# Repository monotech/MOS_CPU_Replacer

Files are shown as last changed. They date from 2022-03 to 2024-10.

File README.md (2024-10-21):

# Monotech PCs - MOS CPU Replacer  
**Replace rare/expensive/unreliable MOS CPUs**  
6510 *(C64) (8500 is same as 6510)*  
6510T *(1551 floppy drive)*  
8501 *(C16, C116, Plus/4) (7501 is same as 8501)*  
8502 *(C128)*

Licensed under Creative Commons BY-SA: (https://creativecommons.org/licenses/by-sa/4.0/)

If you want one, check my store for stock: (https://monotech.fwscart.com)

The above four CPUs have the same dies I believe, with just different internal pads exposed to the DIP-40 pins.  
It's a standard 6502 die, with an added 8-bit bidirectional I/O port, tri-state bus buffers, and an AEC latch enable for 8501 mode.

This device uses a standard 6502 CPU, and implements the extra functions using discrete logic - no programmable parts.  
Standard 6502 CPUs are abundant and cheap, and produced by many manufacturers (Rockwell, UMC, Synertek, MOS, etc).

You can use a 65C02 or W65C02, but this is untested, and will cause compatibility issues with some software at the least, or not work at the worst.  
If using a WDC W65C02, you must cut jumper W.

Build instructions are on the back of the PCB. This document is for clarification if you find it unclear.

It may struggle to fit inside a C116 or Plus/4 due to height, so for these machines you should solder the 6502 directly to the module's PCB, or solder the module directly to the C116 or Plus/4 motherboard.  
For C16, height is not a problem.

It is tested to fit next to a PLA20V8 replacement in a 250407 board. Other oversized replacement boards may interfere and require installing the module in an extra socket to raise it up.

Status as of Rev1:
-

- :heavy_check_mark: 6510 config: Tested working in a C64 and C64C with a wide range of software. In one scenario, it was discovered that it causes graphical glitches when used in a C64 with a C0pperdragon video conversion device (which watches the VIC-II pins). This was on Rev1. It may or may not be resolved on Rev2.
- :heavy_check_mark: 6510T config: I don't have a 1551, but someone else has done some basic testing in their own, and it works.
- :x: 8501 config: Tested working in a C16 and a Plus/4, but it has been found that at least one program crashes on a 64K-modded C16, that doesn't crash with a real 8501.
- :x: 8502 config: Works but has graphical glitches, likely due to a timing issue, so should only be built if you plan to help me diagnose this. For 8502, you must install a 2MHz-rated CPU (such as 6502A).

Known issues:
-

- A local enthusiast has discovered that using this adapter in 8501 config in their 64K-modded C16, results in Slipstream (https://psytronik.itch.io/slipstream) hanging, and causing resets to stop working (need a power cycle). One other person has confirmed this, and confirmed it doesn't happen with a real 8501, so the issue is with the MOS CPU Replacer. I will look into possible causes and update this page if a solution is found. Testing the C64 version of Slipstream in a C64 works fine with either a real 6510 or the MOS CPU Replacer in 6510 config.
- One user reported that it causes graphical glitches when used in a C64 (6510 config) with a C0pperdragon video conversion device (which watches the VIC-II pins), but works well otherwise. This was on Rev1. It may or may not be resolved on Rev2.
- I am sometimes working on improving the device, and hopefully reaching 100% compatibility.

---
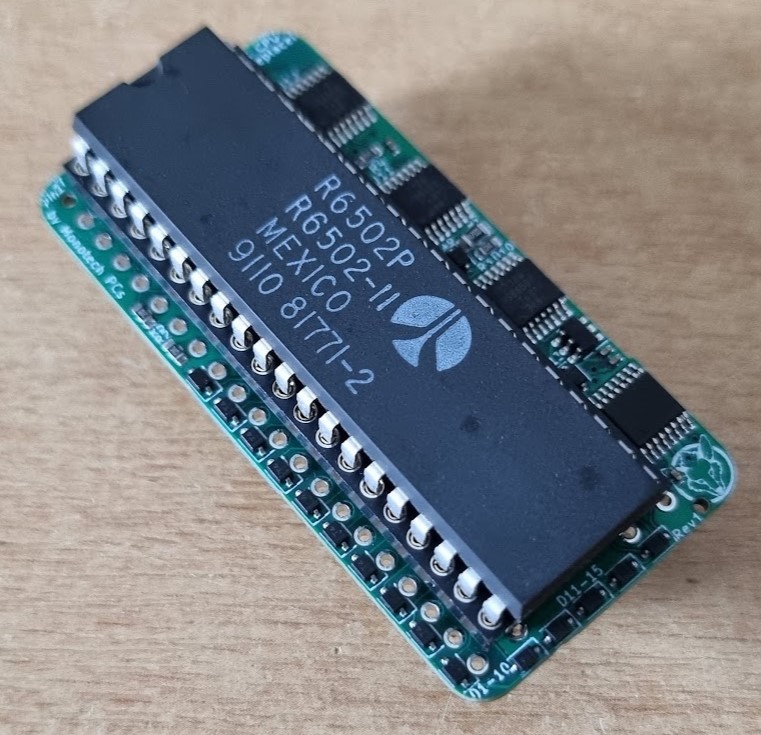
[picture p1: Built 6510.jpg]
Built in 6510 config


Instructions:
-

1. Solder the solder-jumpers first (red dots).
1. Solder two 20-pin round-pin headers (cyan rectangles). (Not 21-pin!)
1. Solder the DIP-40 socket (yellow rectangles).
1. Install the 6502, and test the device.
    Don't install the device backwards or misaligned!

**The example picture below is for 8501 config (Jumpers: C, Headers: E). Steps 1 and 2 are different for the other three configs.**

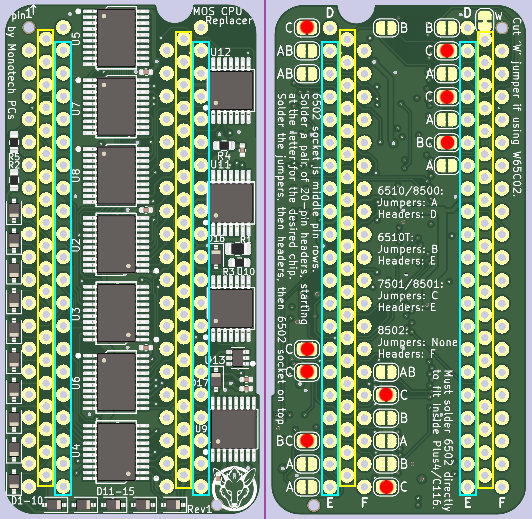
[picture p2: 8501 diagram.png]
Diagram for 8501 config


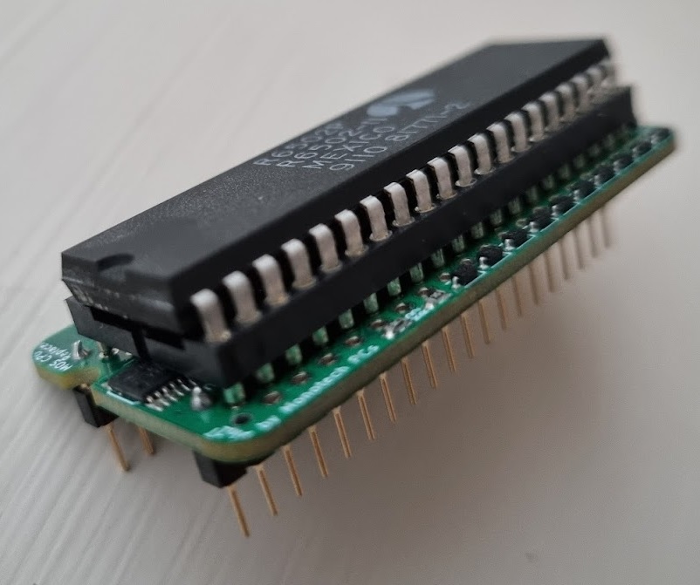
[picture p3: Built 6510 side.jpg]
Built in 6510 config, side view


**Troubleshooting**

- See the Known Issues section above.
- Double-check for shorts and that you soldered the correct solder jumpers.
- Crappy single-wipe IC sockets that Commodore used, can cause a lot of headache. Replace them.
- Your 6502 from Aliexpress/eBay may be fake or faulty. Sometimes they are actually 65C02 that have been re-marked as 6502.
- Some models of 6502 may be incompatible - I haven't tested all of them.
- I haven't tested every combination of Commodore motherboard revision, PLA replacement, marginal IC, or timing-sensitive demo.

**Changelog**

- Rev 2: used an unused HCT126 gate to buffer the PHI2 output, improving compatibility. Only affects 6510 and 6510T configurations which actually have a PHI2 output.
- Rev 1: First version

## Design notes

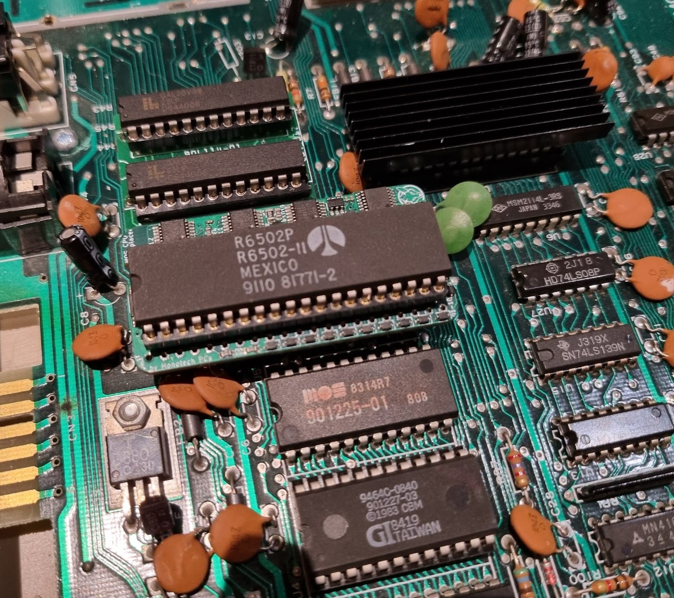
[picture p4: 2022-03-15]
Inside a C64.jpg

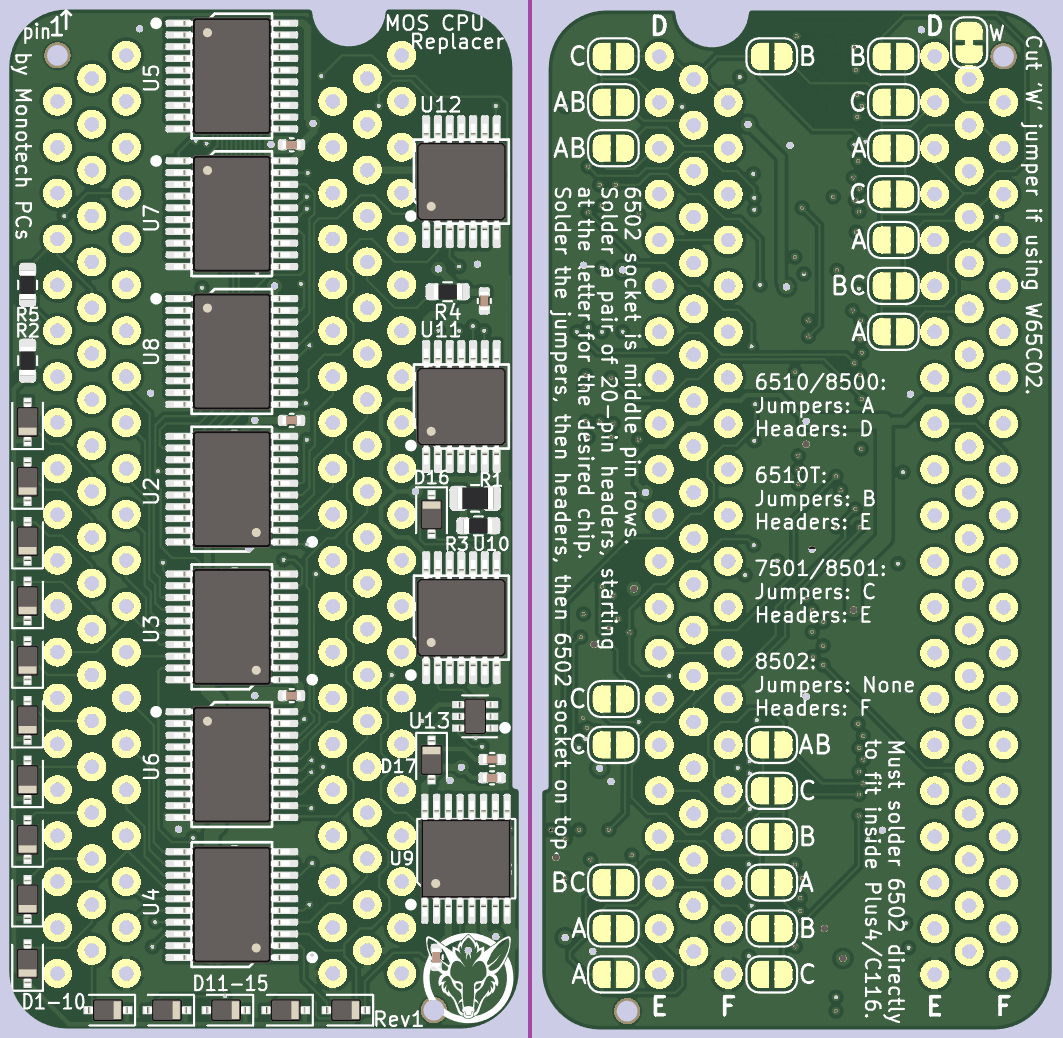
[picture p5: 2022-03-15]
Bare diagram.png

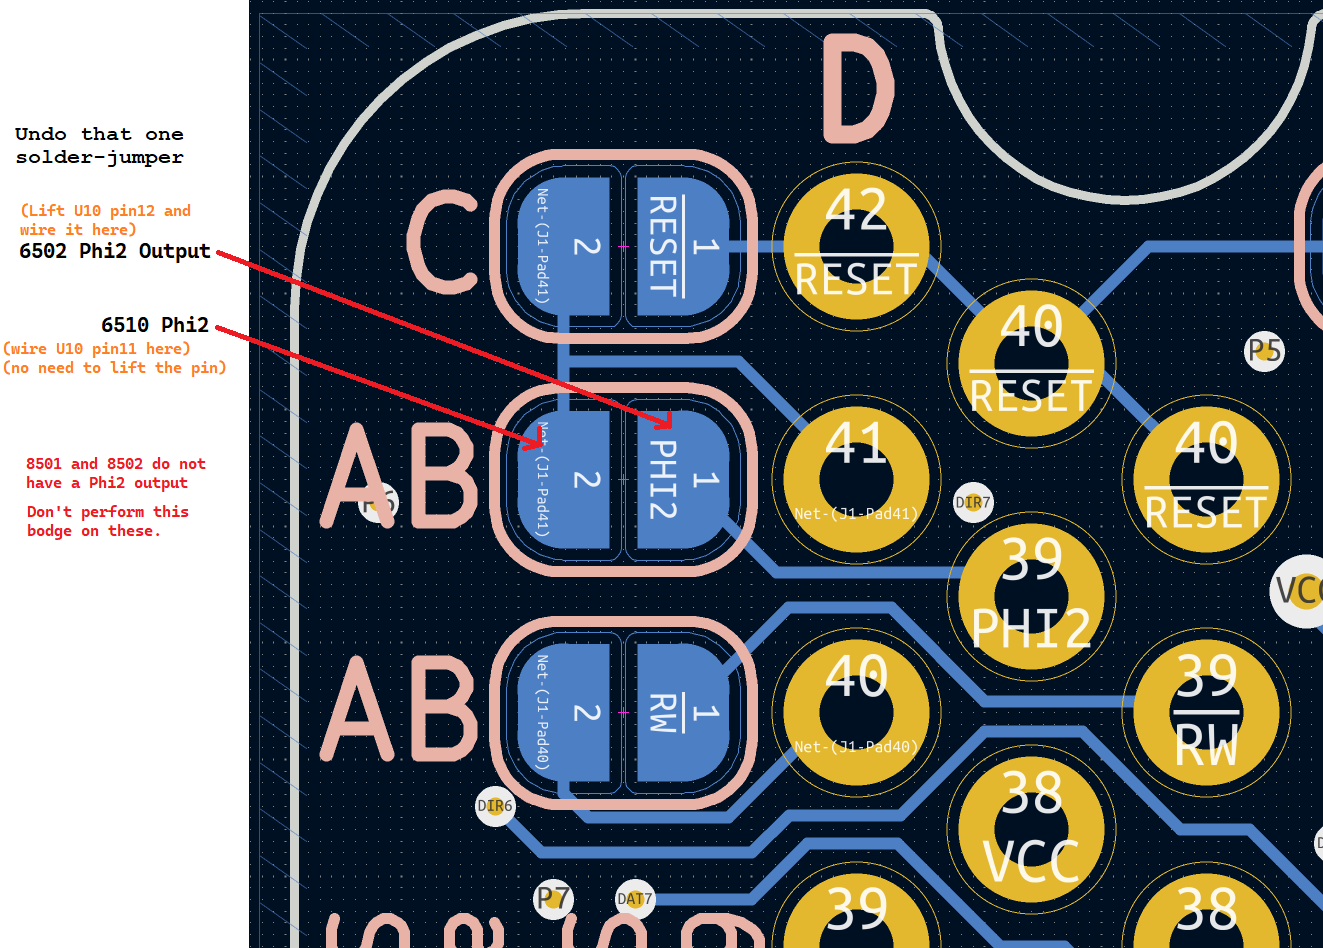
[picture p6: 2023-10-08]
Bodge to upgrade Rev1 to Rev2 (Phi2 buffer mod).png

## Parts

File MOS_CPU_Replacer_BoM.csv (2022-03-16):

Qty | Reference | Part model | Footprint | Mouser part number | Digikey part number | Notes
7 | C1-7 | 100nF | 402 | 187-CL05B104KP5NNWC | 1276-1510-1-ND | C7 only needed for 8501
17 | D1-17 | 1N4148W | SOD-323 | 241-1N4148WSR100001 | 1655-1359-1-ND | D17 only needed for 8501
1 | R1 | 470 | 805 | 603-RC0805JR-07470RP | A130132CT-ND
4 | R2-5 | 10k | 603 | 603-RC0603FR-1310KL | 311-10KGRCT-ND | R4 only needed for *65C02 support
5 | U2-6 | 74HCT245 | TSSOP-20 | 595-SN74HCT245PWR | 296-8404-1-ND
2 | U7-8 | 74HCT273 | TSSOP-20 | 595-SN74HCT273PWR | 296-8409-1-ND
1 | U9 | 74HCT138 | TSSOP-16 | 771-HCT138PW118 | 1727-2050-1-ND
3 | U10-12 | 74HCT126 | TSSOP-14 | 771-HCT126PW118 | 1727-6619-1-ND
1 | U13 | 74LVC1G373 | SOT-363 | 595-74LVC1G373DCKRG4 | 296-18775-1-ND | U13 only needed for 8501
1 |  | 40-pin round-pin header |  | 872-920-0172-01 | 1988-1163-ND | Cut it in half
1 |  | DIP-40 round-pin socket | DIP-40 | 575-11044640 | ED3033-ND
1 |  | 6502 CPU | DIP-40 | N/A

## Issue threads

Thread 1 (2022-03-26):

BOM file

repetto74, 2022-03-26:
Hi,

Is it possible to add a BOM list to the project? It is difficult to identify the correct SMD packages of ICs and other passive components needed to build it.
Thanks
Rick

repetto74, 2022-03-26:
Sorry the BOM is there I did not see it :-)!

monotech, 2022-03-26:
No worries :)

If you missed that, be sure not to miss the Readme.md!

This project is not suitable for use as 8501. I am working on that, and will be releasing a new version once I fix it. I cannot find any software that makes 6510 config fail compared to a real 6510, but it may still be out there! Be sure to report back if you find a reproducible compatibility issue.

repetto74, 2022-03-27:
Hi,

Thanks for your advice :-). I am willing to build it as a replacement for
the 6510 only. I will for sure build another pcb for the 8501 once issues
will be fixed ;-)

Regards,
Rick

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

--
Riccardo Repetto
@ AppleWorld...

repetto74, 2022-03-27:
Hi again,

I have tried to source the IC required for the 8501 version of the board
with no luck. I know I will not build that version at the moment but is
there a valuable alternative to the 74LVC1G373?
This latch is hard to find and out of stock apparently :-)

Regards,
Rick

On Sun, Mar 27, 2022 at 1:04 AM riccardo repetto ***@***.***>
wrote:

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

--
Riccardo Repetto
@ AppleWorld...

monotech, 2022-03-27:
I'd suggest waiting for the new version before building - the parts may
change quite a bit.

No known compatible alternatives for LVC1G373 at this time.
If you wish to build for 6510 config, just don't install the LVC1G373.

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

repetto74, 2022-03-27:
Hi,
Understood I do not need to populate the pcb with the latch for 6510 implementation.
Thank you for this project it looks really cool and fun to do ;-)

Rick

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

Closed 2022-03-26.

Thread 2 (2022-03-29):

Consider a "This Side Up" label

DusteDdk, 2022-03-29:
Entirely my own fault, but after being presented with blank screen I discovered that my intuition about the orientation was wrong (I should have consulted pictures before I started, but I was lulled into a false sense of security by all the instructions and it slipped my mind) :)

Still, it might be nice if it's possible to find a little spot for "This side up" in the next revision.

Also, thanks for doing all this awesome stuff! :+1:

monotech, 2022-03-29:
Oh dear! "This side up" label sounds good. I'll add it to the next version
which I'm working on (with fixed 8501 support at least).

It may work if you desolder and install things where they should go.
Depends where things really ended up being wired.

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

DusteDdk, 2022-04-02:
Yeah, I guess it should, it was exactly "upside down" (that is, the surface mount ICs were on the bottom instead of the top) but the notch was in the right orientation :) unfortunately, I entirely scewed up the desoldering process, so I'll just order another kit when/if they become available again xD Thanks for adding the label, it will help someone in the future I'm sure. No idea how I didn't stop and think "Hey, which side of the PCB should I put the socket on" :D

Closed 2022-04-02.

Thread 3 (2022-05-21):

Can't get mine working?

dwestbury, 2022-05-21:
I had a round of these made by JLCPCB, with the goal of using them as a 6510 replacement for some new DIY C64 builds, but so far I haven't been able to get them working?

I've tried several known working 6502's - some from AliEx, but others from working 1541 disk drives, but all are failing with similar errors...

The C64 shows a black-screen, and a Deadtest cart won't even work.

I also tried running some tests using a Backbit tester on the MOS 6510 setting, but this is showing failures on:
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

The only DIY bits that JLCPCB didn't do for me were the jumpers, the pin headers and the machine pin socket, which I hope I've done correctly (see images)...

Appreciate any assistance...

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

monotech, 2022-05-21:
Hello

Your MOS 6502A definitely have fake markings, but most fake marked chips
still work, although some are marked with a different model.
Even if yours are actually 65C02, they will work to boot the C64, but many
games and demos would crash.

Where did you get your HCT273s from? Their markings also look dubious.

Cheers
JD

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

dwestbury, 2022-05-23:
Thanks @monotech - Appreciate the reply.
I've tried a few different 6502's, including a couple that I pulled from working 1541 drives, all have the same issue.
Due to supply chain issues, JLCPCB didn't have the HCT273's, so I wound up sourcing these from an eBay seller.
I'll have to try out some chips another source to see if they're the issue...

monotech, 2022-05-23:
I suggest getting a TSSOP to DIP adapter and trying your HCT273s in a logic
tester (such as a TL866 programmer).

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

dwestbury, 2022-05-28:
@monotech - Good idea. The adapter shows that the 273's are working...

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

monotech, 2022-05-28:
Hmm.. I'm not too sure sorry :/
I can only think of ensuring the HCT273s are soldered correctly since you hand-soldered them, and they're fine pitched.

ewsz, 2023-05-05:
>

The 6502 in your 1541 is most certainly a MOS 6502 which can comply with 1MHz. You need a CPU at least good for 2MHz - like a MOS 6502A or an R6502A. The CPU on the photo should be fine, of the markings are real.

dwestbury, 2023-05-10:
Well, this update is coming nearly ~1 yr later because I had put this project on hold to work on other things.

In short, I simply hadn't shorted the"**W**" pad on the bottom of the board.

Once that was done, my modules are working perfectly now...

monotech, 2023-05-10:
The PCB has W shorted by default with a track. Perhaps you cut it at some point in order to use a W65C02S ?

dwestbury, 2023-05-10:
The documentation does indeed show that "W" should be shorted by default, but I must have manufactured an older PCB rev, because _none_ of boards I had made last year had this pad closed be default?

I picked the project up again a couple of weeks back because I had an itch to get this going again, which is when I noticed the oversight on my part. Once I added the short, all of my boards worked...

This is a great project and a valuable asset that will help to keep the C64 alive, so thank you for that!

Closed 2023-05-10.

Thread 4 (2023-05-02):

High Impedance On Data Bus

ewsz, 2023-05-02:
Hi

Great project. I like it a lot. Finally somebody who addresses the issue in an open source project.

I just have doubts about how the high impedance on the data bus (OE on D0-D7) is being implemented. Actually it should be always high impedance when AEC is low. When accessing the port of the CPU in the write case it should be low impedance in the in the write case and high impedance for read case (the CPU would not read from the bus in this case).

It is actually correct that the CPU writes through to the boards memory in the write case. It does not really make a difference for a C64 or a Plus/4 but on a C16 where the memory areas are mirrored, the effect is actually observable. Not sure whether this could also simplify the board.

May I miss something in the schematics, but AEC is active high - so the bus of the CPU is connected to the system bus, when it is high, not when it is low; the OE of the 74245 is active low - it will assume high impedance state on high on OE, where according to the CPU specification AEC the CPU bus should be connected. Quote from 6510 datasheet:
"- Address Enable Control (AEC)
The Address Bus is valid only when the Address Enable Control line is high. When low, the Address Bus is in a
high-impedance state. This feature allows easy DMA and multiprocessor systems._"

Hope it helps

Hope it helps.
Regards

monotech, 2023-05-04:
Cheers, glad you like the project! Yea it would be nice to iron out any remaining compatibility issues.

Sorry, I have a little confusion when reading your message due to polarity naming.
In my schematic, I have named the 6510 pin "/AEC". Later in the schematic, there exists an inverted version of this called "AEC".

At present, the device's D0-7 bus goes high-impedance when /AEC goes low.
When /AEC goes high, The D0-7 bus transceiver becomes active, unless the current address is 0000 or 0001.

Are you suggesting I should control the D0-7 bus transceiver with AEC (that's inverted /AEC) alone? That could simplify things slightly.
I am not really sure about the architectures of these machines, and how the C16 differs.

Unfortunately, the 6510 datasheet and related same-die chip datasheets, seem incomplete or rough. The purpose of the AEC pin is different in the 6510 datasheet compared to the 7501 and 8502 datasheets (6510T datasheet is missing).

ewsz, 2023-05-04:
I am quite familiar with the TED-architecture.

AEC on this architecture is serving the purpose to allow the TED to read character and graphics data from the DRAM. During this phase any interference by the CPU on the bus (address, data, RW) is detrimental. I think the same is true for the VIC-II but I am less familiar. For the VIC-II it should be less critical because it does not use alternating clock rates.

I guess page 27ff of https://www.pagetable.com/docs/ted/TED%20System%20Hardware%20Manual.pdf helps you to understand the architecture. If AEC goes low, address bus, data bus and RW are going high impedance (T_AEDT, T_AEAT, T_MRWS), ensuring the CPU is not interfering with the read cycles of the TED. I would be surprised that it would be different for 6510 and the VIC-II, but I am less familiar with these devices.

If you hold that against the timing of a R6502 (http://datasheets.chipdb.org/Rockwell/6502.pdf, page 10ff), the R6502 guarantees T_DSU + T_HW > 90ns to retain the RW low starting from a falling PHI0 in the write case for 2MHZ and does not guarantee to pull it high afterwards - though I assume that is what is happening. Whilst the TED will pull AEC to low immediately, if it should deem to need the bus. This would leave the but in limbo with an active write signal.

BTW, according to the first document GATE-IN (MUX) does not set RW to high impedance but to high. Only in the case that AEC is also low it will result in a high impedance RW line; AEC is indicating this state. I am aware that there are different interpretations on the matter, but that is what the timing diagram is stating.

On the CPU ports I have been wrong actually; the underlying RAM should not be written to.

I do not think you have to model all of this exactly. The essential bits appear to be that all lines get high impedance based on AEC. RW needs to get pulled up based on GATE-IN (MUX). I can not envision any reasonable use of the two RAM bytes lying under the CPU ports, but as I stated: I was wrong on the matter; technically they should not be written to.

Hope it helps.

PS.: For the 6510T of the 1551 your board appears to be overkill. The AEC is hooked up to +5V. I think the port is always output, but I would have to check the specifications to be sure,

monotech, 2023-05-04:
Thanks for the info!

The first document you linked, states that the AEC pin on a 7501 affects the address bus. It doesn't mention data bus or RW line like the 6510 datasheet.

In my design, Gate-in latches the RW output for 7501. Latching is different to setting RW high (unless in all practical use cases Gate-in is only being asserted when RW is currently high). Perhaps this is a mistake. I don't own any TED systems at the moment to test unfortunately.

I have just updated the files to Rev2, which includes a small change (only affects 6510 and 6510T).

Regarding 6510T, this config is still untested, as I don't have a 1551. I can see how this board would be overkill for that. Due to the low demand for 6510T, I won't bother making a simplified version in this case.

Cheers!

ewsz, 2023-05-04:
Well, on the TED architecture the CPU has to set the data bus to high impedance on AEC low; that is stated on the pages I referred to. As long as your HC bus transceivers only compete against LS chips, the LS chips will win anyways. That picture may change if you employ HC chips on the board; e.g. for a memory expansion.

The 6510 datasheet (http://archive.6502.org/datasheets/mos_6510_mpu.pdf, page 4ff) shows the data bus high impedance during PHI2 low; that period exceeds the period of AEC low. Actually it appears that AEC going back to high is triggering PHI2 to raise again. But you do not have PHI2 on your board. So ...

Trust me. The data bus has to be high impedance, if AEC is low.

The GATE-IN signal is actually service the purpose to prevent the RW signal from going low. This will also very fast RAMs allow not to pick up wrong write signals. But I think your interpretation of "gating" the RW signal is compliant with the specification.

Hope it helps.

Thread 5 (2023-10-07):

incompatibility with C=64 and Stix

giobbino, 2023-10-07:
_(I was sure I already wrote that, but I can't find my issue so maybe I didn't write it yet actually. Am I'm growing old? LOL)_

After some months of use, I've found a small glitch using the game STIX with a 6k cartridge based on Magic Desk
(this is the link to the cartridge project, if needed:  https://github.com/wagiminator/C64-Collection/tree/master/C64_Cartridge_64k_256k)

This is the link to the PRG I used to build the cartridge:
https://www.planetemu.net/rom/commodore-c64-games-d64/stix-1983-supersoft-4

I tried it with two different C=64 and I have the same behavior.
- With an original MOS 6510, the "laser wave" is correctly moving on the screen
- With the CPU Replacer, the wave falls in the bottom-right corner and there stays forever.

I'm not sure why is doing that... all the other programs, games, cartridges and peripherals seem to work fine, at least to this moment.

monotech, 2023-10-07:
Thanks for letting me know!
What revision is your MOS CPU Replacer PCB?

giobbino, 2023-10-07:
I can't see any rev. code on the PCB, but inside the project Zip file from GitHub talks about Rev1...

giobbino, 2023-10-07:
BTW I didn't think to test it loading the program from a disk / sd2iec. I will try that asap.

monotech, 2023-10-07:
Revision is on bottom right of PCB, next to logo.
Rev2 is latest. It came out 5 months ago. Most stock I've sold in my store after that was Rev2 PCBs.
Changelog is at bottom of github.com/monotech/MOS_CPU_Replacer
Rev2 improves compatibility with some things in 6510 mode.
A Rev1 can be upgraded to a Rev2 if you can do small soldering. Or I can send you a Rev2 board for cost of postage.

giobbino, 2023-10-07:
_Revision is on bottom right of PCB, next to logo._

Gotcha. I didn't see it, sorry for that.

_A Rev1 can be upgraded to a Rev2 if you can do small soldering._

Oh, well, I mounted all the small smd on my own, maybe I can also patch it, if my eyes cooperate LOL. Maybe.
Is there any instructions about that?

I got 10x PCB Rev1, so it would be fine if I can patch all of them.

monotech, 2023-10-08:
I have added a diagram showing how to mod the PCB to Rev2.[
](https://github.com/monotech/MOS_CPU_Replacer/blob/main/Bodge%20to%20upgrade%20Rev1%20to%20Rev2%20(Phi2%20buffer%20mod).png)The most difficult part is lifting a TSSOP pin - you only get one try or the pin will break.

giobbino, 2023-10-08:
Well, I lifted the pin without problem... just to break it while I was soldering the wire.

So I removed the IC, cut the trace that connect pin #12 to pin #13, and soldered a new IC. Then I soldered two thin wires to pin #11 and #12 (it was quite a nightmare) and then to the jumper pads, as shown in your picture. I then check everything with the multi-meter, just to be sure I didn't add some short circuit.

And... nothing, black screen.

Of course there's some mistake I did there, or in another place: this was a new board I was making, and I didn't test yet. I didn't want to make the fix on my Rev1 working board.

...but honestly, this fix is beyond the skill of my eyes, even using a double magnify lens on my head. Simply, I can't clearly see what I'm doing.  I'm growing old LOL

Since I haven't a real need for this adapter *YET* (I'm sure I will need it, I'm almost running out of spare 6510 etc.), I will wait for a possible new revision, and later I will buy some new boards.

In any case, thanks for you help - and of course for your awesome project!!!

giobbino, 2023-10-08:
UPDATE: I can't admit with myself I can't make a simple fix, so I spent the rest of the afternoon looking at the board, until finally I found and fix the issue. Now it's working...   ...and the issue with STIX is present in the Rev2 too. I tried both with the cartridge and loading the PRG from SD2IEC.

Rev3 on the horizon? LOL

monotech, 2023-10-08:
Thanks for testing that! Unfortunate to hear there are still some
incompatibilities. What model of 6502, and from what source?

No plans for a Rev3 yet as I am unsure what to check next and have a lot to
do.

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

giobbino, 2023-10-08:
I tried with a surely legit MOS 6502 (1983) I removed from one of my PET and  two R6502, one surely legit I dated 1984, and another "recent" (2010) that should be legit too. Same issue.

The incompatibility on this very game isn't a big deal, of course. But I'm guessing if it can cause some issues in other circumstances, more difficult to detect.

Of course no need to be in a hurry for a fix, we're talking about 40 years old computers, it's just hobby LOL  - and the adapter work with (almost) all programs, afaik - I used it extensively for months.  But it would be nice to understand what's going on.

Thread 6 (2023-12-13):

Problems with DIRECTORY command on Plus/4

perhof, 2023-12-13:
I've built several revision 2 CPU replacers. I've had JLCPCB assemble everything except the ICs which I've sourced from Digikey/Mouser and soldered myself. The pitch is not a problem.
The adapters that I've configured for C64 work very well. I haven't found any compatibility problems there yet.

It's the ones I've built for the Plus/4 that are having an issue.
The issue I'm having is with the DIRECTORY command on the Plus/4.
The command returns only one charcter or sometimes a line or two from the directory before returning to the READY prompt. It's not 100% consistent except that it never works fully.
The DIRECTORY command reads a disk directory to the screen one byte at a time instead of loading the full directory into memory.
LOAD"$",8 loads the entiry directory to memory and that works fine and loading programs works fine too. At least all the programs I've tried.

-Tested three different CPU Replacers (all are Rev 2)
-Tried in three different Plus/4 computers (all three are new to me and had dead CPUs)
-Tested several AliExpress 6502's that have been verified to work fine in all other applications including some C64 demos that don't work with all 6502's and I have tried with 6502's out of 1541 drives as well.
-Tested with SD2IEC, Pi1541 and NLQHD drives.
-Tested different Kernals: Rev 5 (US), Rev 4 (Swedish) and JiffyDOS.

The @$ JiffyDOS command which also loads the directory to screen works fine but the DIRECTORY command fails in JiffyDOS too.

I don't have access to a genuine 7501 or 8501 so I can't verify that it is indeed the CPU replacer that is causing this issue. I'm hoping someone else can try to reproduce the issue, otherwise I'm out of ideas.

monotech, 2023-12-14:
Hello, and thanks for contacting.
Sorry to hear you're having trouble with the MOS CPU Replacer in your
Plus/4. That's quite a peculiar bug.
Yea only 6510 mode seems to be reliable. I haven't heard of your
specific issue but I'll try to get someone who owns a Plus/4 to try it
and compare with original 8501. If it is indeed reproducible, it could
give clues perhaps.
There are more expensive FPGA-based implementations of 8501 that seem
to be bug-free. Likely a signal timing issue.

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

perhof, 2024-02-11:
I've been using the Plus/4 a bit more and found some more things that don't work. Some fastloaders don't seem to work and the JiffyDOS @$ command can hang sometimes too.
I have now been able to try with an original 8501 and the things that don't work with the CPU replacer and a 6502AD work just fine with the 8501 so there's definitely something with the replacer or with the 6502's that I'm using.

SteveGuidi, 2024-03-19:
I can also confirm that something is awry when using the C16 and Plus/4 version of JiffyDOS with the adapter.

- Directory listings sometimes hang mid-listing and require a system reset to recover, as noted in this thread.
- Using the wedge to display a SEQ file sometimes prints nonsensical characters.

I'll report back when I use a proper 8501 to verify these issues.

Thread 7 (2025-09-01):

Work in progress on c128d need some advice

banman11, 2025-09-01:
Hello monotech,

I hope you are well.

I thought I'd use this forum as the focus of a discussion with you i have had via email.
I might make it easier.

I have been testing your impressive 8502 CPU replacement board on a c128D.

I have been some what successful in isolating and to a large part remove the glitches that you have referenced on your website.

https://monotech.fwscart.com/product/mos-cpu-replacer-(6510-8501)

Here's the most current YouTube video to date of it in operation...

https://youtube.com/shorts/SQAN0RQLAYI?si=EhMrCFpY7BmAMOf7

Now I have several questions about my observations.

The EPROM used here although a good candidate I my mind wasn't actually the EPROM I intended to make this work.
In fact the EPROM that I had in mind were actually worse than I expected.
Both these EPROM's have the same timing speed of 90ns.

So there is  this theory I have been thinking on. Now I have really no idea if I'm even close to hitting the mark on this...

The Devil Is in the Details
Even among chips with the same speed rating, manufacturers have their own specific timing specifications that can vary slightly. These small differences are often what separate a working chip from a non-working one in a marginal system like your C128 with a third-party CPU board.

The key is to look beyond the general Address-to-Output Delay (t AA) and examine other critical timing parameters in the datasheet:

Chip Enable to Output Delay (t CC ): The time from when the chip is selected to when data is valid on the outputs.

Output Enable to Output Delay (t OO): The time from when the output drivers are enabled to when data is valid.

Output Disable Time (ttD ): The time it takes for the chip to release the bus after it is deselected.

It's likely that the Fairchild EPROM has a specific combination of these parameters—perhaps a slightly longer tDF

 —that allows the CPU to fully relinquish the bus before the EPROM starts driving the data lines. Other 90ns EPROMs may have a faster ttD , causing them to start outputting data while the bus is still in a contested state.

Please, anybody have any ideas.......

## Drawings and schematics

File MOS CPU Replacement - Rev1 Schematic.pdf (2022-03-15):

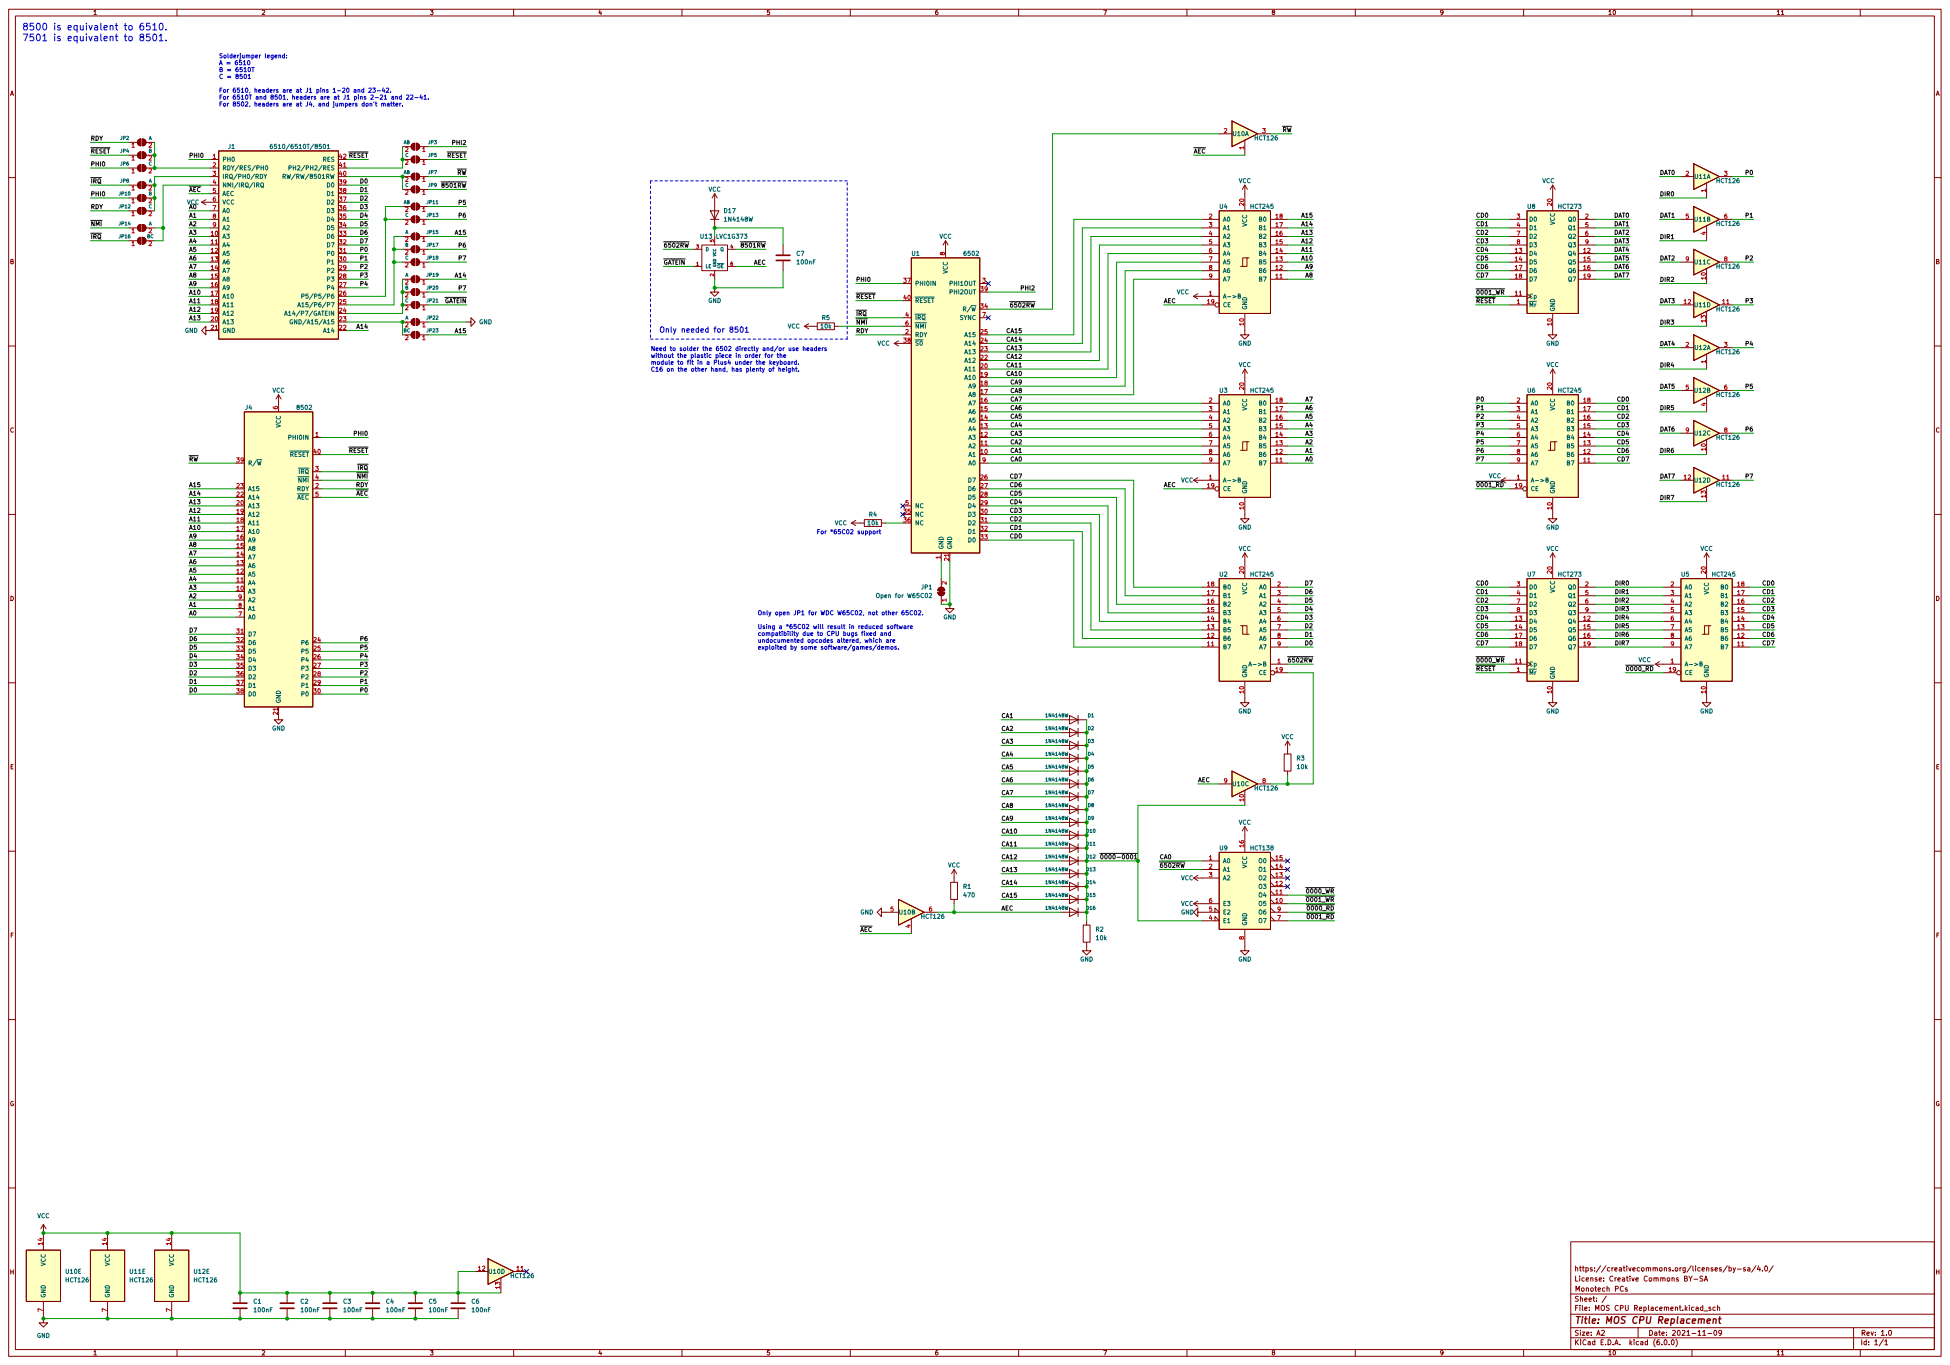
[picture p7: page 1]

Solderjumper legend: A = 6510 B = 6510T C = 8501 For 6510, headers are at J1 pins 1-20 and 23-42.

For 6510T and 8501, headers are at J1 pins 2-21 and 22-41.
For 8502, headers are at J4, and jumpers don't matter.

1 A1 10 A2 11 A3 12 A4 13 A5 14 A6 15 A7 16 A8 17 A9 18 A10 19 RDY 2 A11 20 GND 21 A12 22 A13 23 A14 24 A15 25 D7 26 D6 27 D5 28 D4 29 PHI1OUT 3 D3 30 D2 31 D1 32 D0 33 R/~{W} 34 NC 35 NC 36 PHI0IN 37 ~{S0} 38 PHI2OUT 39 ~{IRQ} 4 ~{RESET} 40 NC 5 ~{NMI} 6 SYNC 7 VCC

Need to solder the 6502 directly and/or use headers
without the plastic piece in order for the
module to fit in a Plus4 under the keyboard.
C16 on the other hand, has plenty of height.

Only open JP1 for WDC W65C02, not other 65C02.

Using a *65C02 will result in reduced software
compatibility due to CPU bugs fixed and
undocumented opcodes altered, which are
exploited by some software/games/demos.

https://creativecommons.org/licenses/by-sa/4.0/
License: Creative Commons BY-SA
File: MOS CPU Replacement.kicad_sch Sheet: / Monotech PCs

Id: 1/1 Title: MOS CPU Replacement

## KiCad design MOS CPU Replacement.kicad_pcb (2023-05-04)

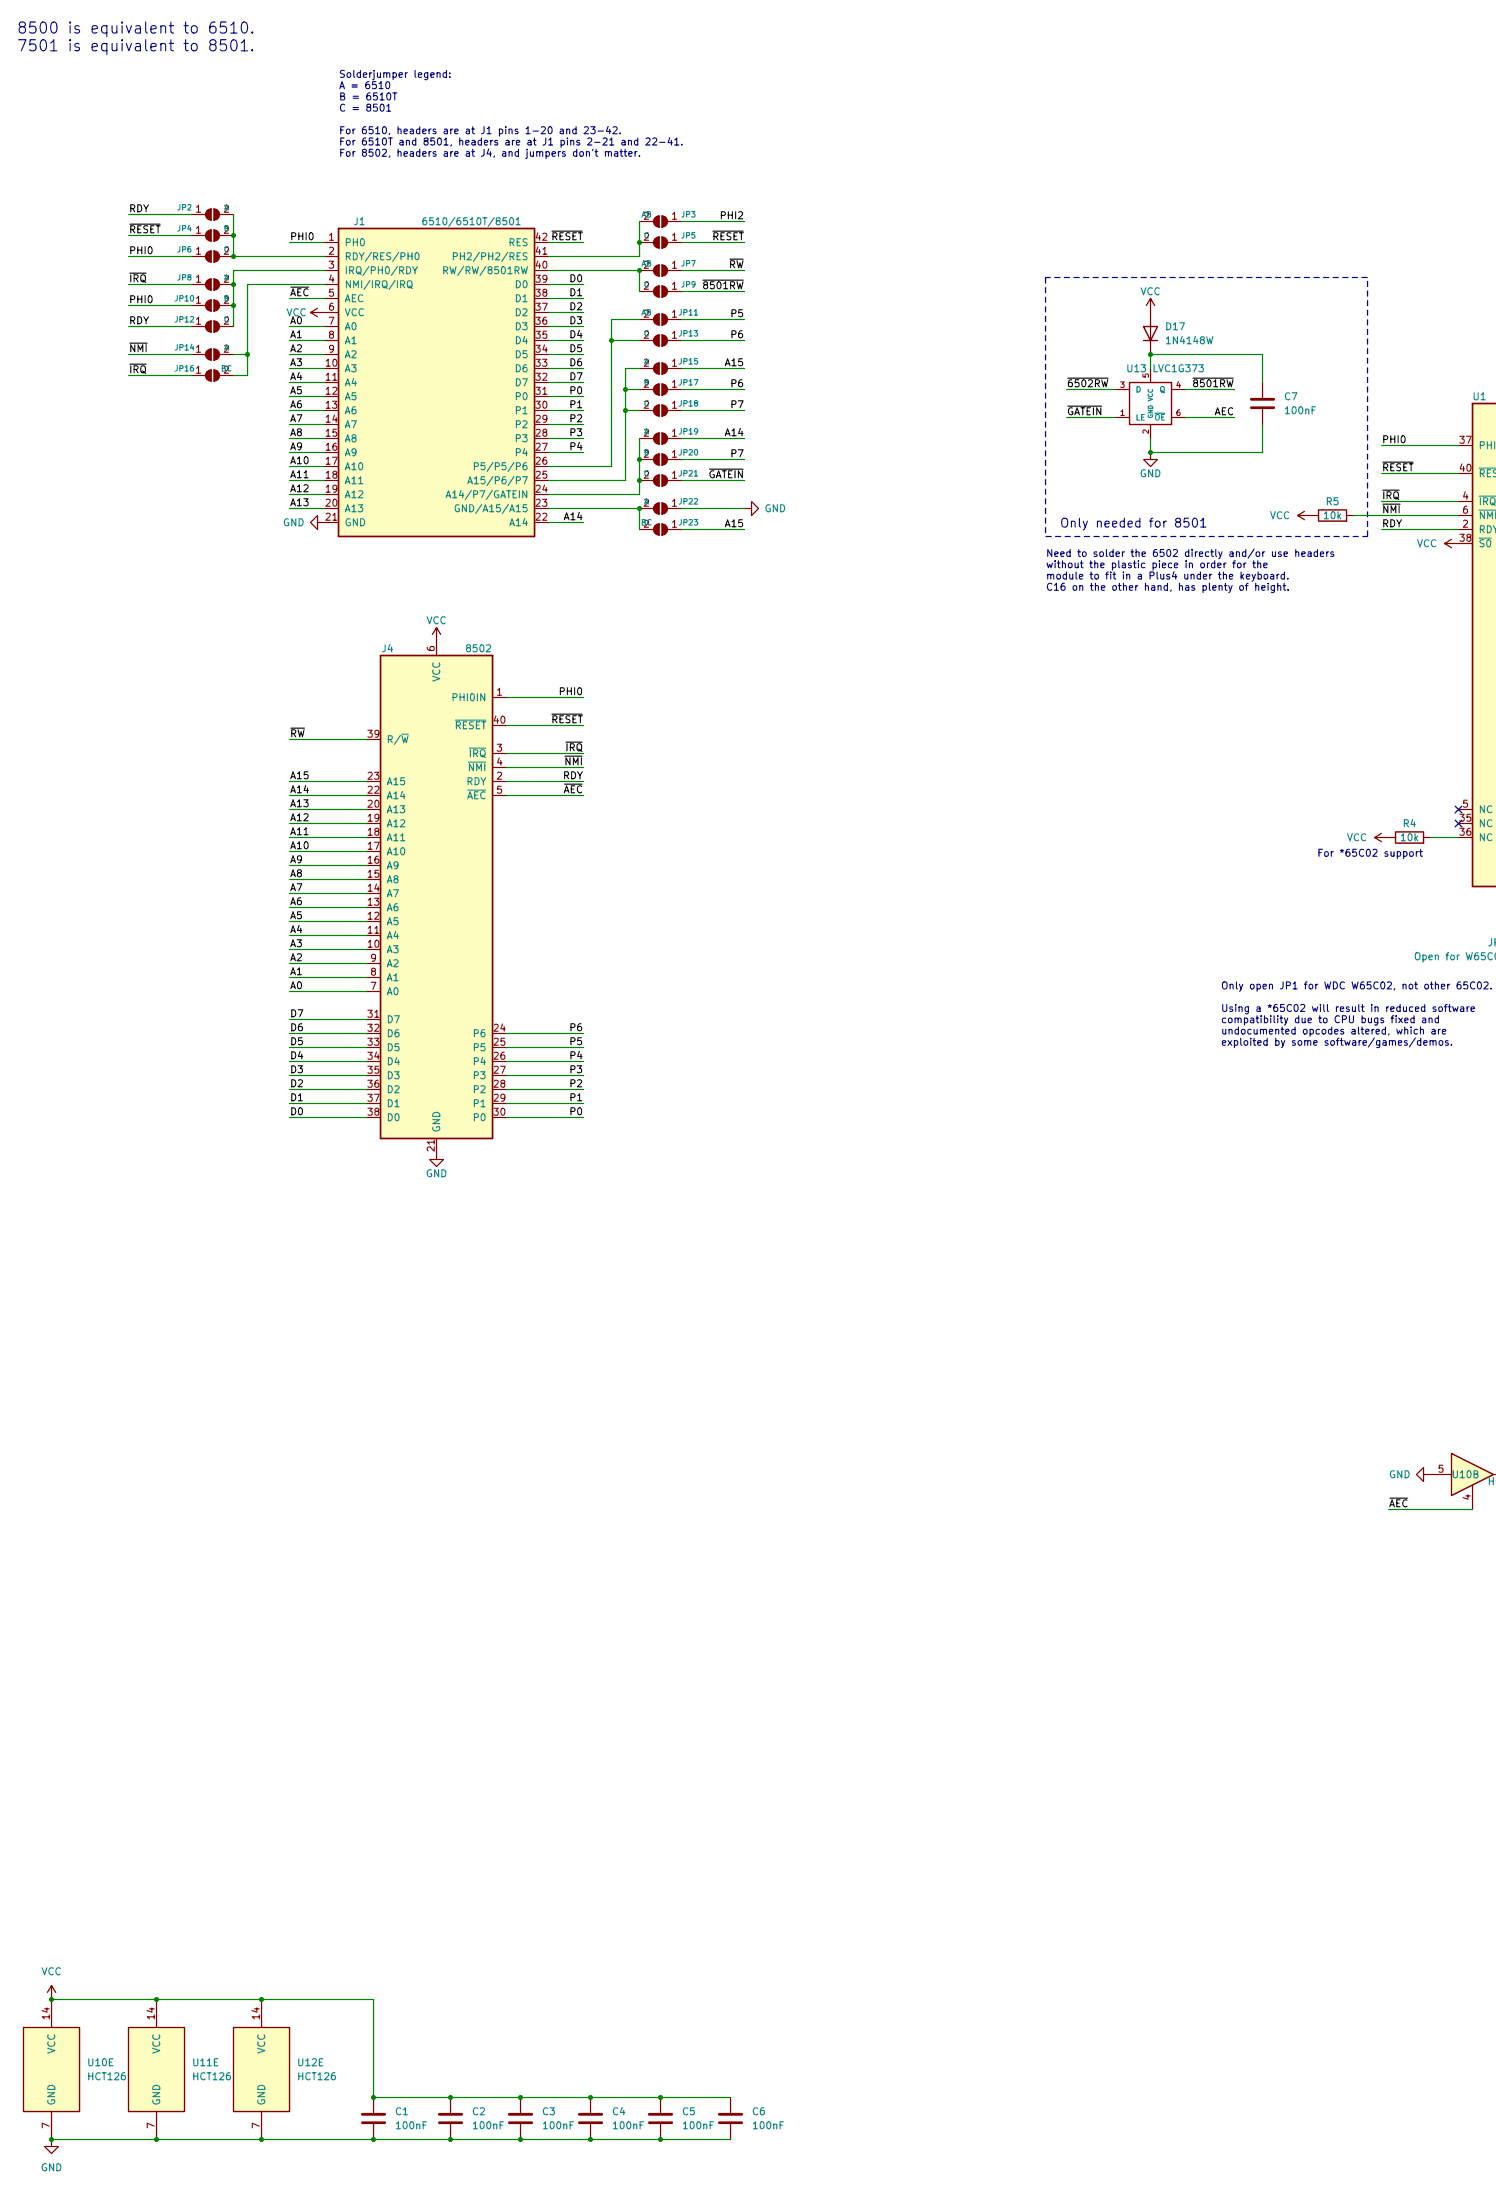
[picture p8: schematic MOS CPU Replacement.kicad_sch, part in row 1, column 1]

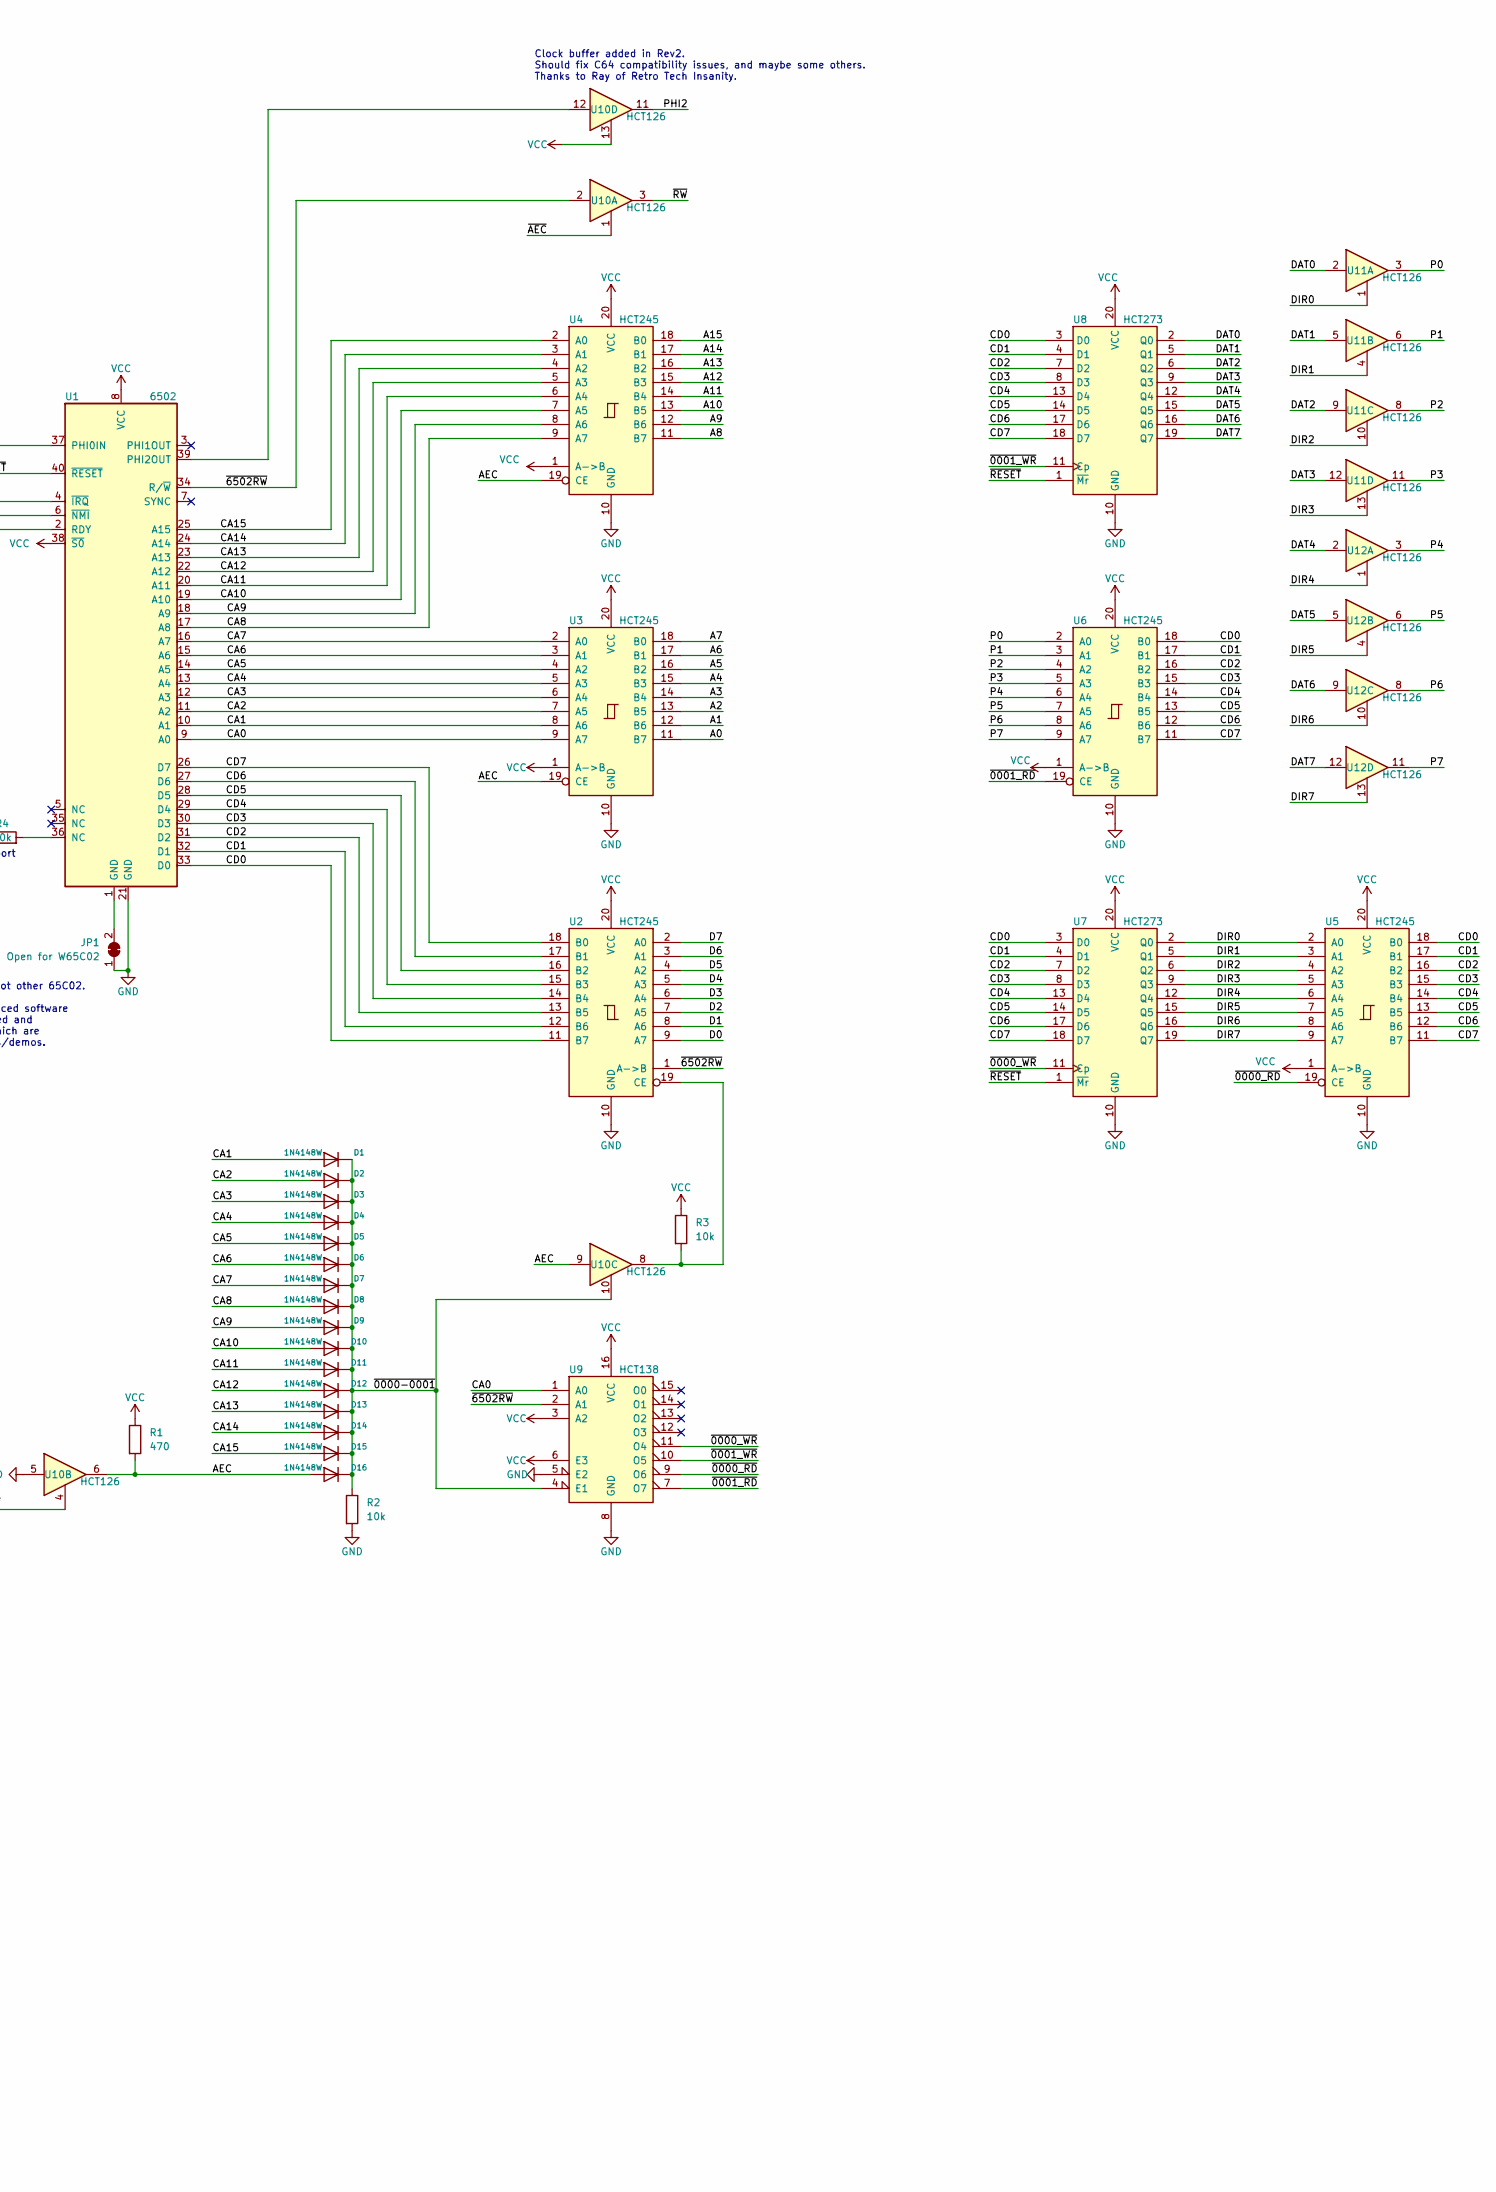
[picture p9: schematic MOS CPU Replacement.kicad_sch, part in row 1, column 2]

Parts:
C1, C2, C3, C4, C5, C6, C7: 100nF; C_0402_1005Metric
D1, D2, D3, D4, D5, D6, D7, D8, D9, D10, D11, D12, D13, D14, D15, D16, D17: 1N4148W; D_SOD-323
J1: 6510/6510T/8501; 6510_6510T_8501_Socket
J4: 8502; DIP-40_W15.24mm_Socket
JP1: Open for W65C02; SolderJumper-2_P1.3mm_Bridged_RoundedPad1.0x1.5mm
JP2, JP8, JP14, JP15, JP19, JP22: A; SolderJumper-2_P1.3mm_Open_RoundedPad1.0x1.5mm
JP3, JP7, JP11: AB; SolderJumper-2_P1.3mm_Open_RoundedPad1.0x1.5mm
JP4, JP10, JP17, JP20: B; SolderJumper-2_P1.3mm_Open_RoundedPad1.0x1.5mm
JP5, JP6, JP9, JP12, JP13, JP18, JP21: C; SolderJumper-2_P1.3mm_Open_RoundedPad1.0x1.5mm
JP16, JP23: BC; SolderJumper-2_P1.3mm_Open_RoundedPad1.0x1.5mm
R1: 470; R_0805_2012Metric
R2, R3, R4, R5: 10k; R_0603_1608Metric
U1: 6502; DIP-40_W15.24mm_Socket
U2, U3, U4, U5, U6: HCT245; TSSOP-20_4.4x6.5mm_P0.65mm
U7, U8: HCT273; TSSOP-20_4.4x6.5mm_P0.65mm
U9: HCT138; TSSOP-16_4.4x5mm_P0.65mm
U10, U11, U12: HCT126; TSSOP-14_4.4x5mm_P0.65mm
U13: LVC1G373; SOT-363_SC-70-6

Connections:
/A0: J1.7 (A0), J4.7 (A0), U3.11 (B7)
/A1: J1.8 (A1), J4.8 (A1), U3.12 (B6)
/A2: J1.9 (A2), J4.9 (A2), U3.13 (B5)
/A3: J1.10 (A3), J4.10 (A3), U3.14 (B4)
/A4: J1.11 (A4), J4.11 (A4), U3.15 (B3)
/A5: J1.12 (A5), J4.12 (A5), U3.16 (B2)
/A6: J1.13 (A6), J4.13 (A6), U3.17 (B1)
/A7: J1.14 (A7), J4.14 (A7), U3.18 (B0)
/A8: J1.15 (A8), J4.15 (A8), U4.11 (B7)
/A9: J1.16 (A9), J4.16 (A9), U4.12 (B6)
/A10: J1.17 (A10), J4.17 (A10), U4.13 (B5)
/A11: J1.18 (A11), J4.18 (A11), U4.14 (B4)
/A12: J1.19 (A12), J4.19 (A12), U4.15 (B3)
/A13: J1.20 (A13), J4.20 (A13), U4.16 (B2)
/A14: J1.22 (A14), J4.22 (A14), JP19.1 (A), U4.17 (B1)
/A15: J4.23 (A15), JP15.1 (A), JP23.1 (A), U4.18 (B0)
/AEC: D16.2 (A), R1.2, U3.19 (CE), U4.19 (CE), U10.6, U10.9, U13.6 (~OE)
/CA0: U1.9 (A0), U3.9 (A7), U9.1 (A0)
/CA1: D1.2 (A), U1.10 (A1), U3.8 (A6)
/CA2: D2.2 (A), U1.11 (A2), U3.7 (A5)
/CA3: D3.2 (A), U1.12 (A3), U3.6 (A4)
/CA4: D4.2 (A), U1.13 (A4), U3.5 (A3)
/CA5: D5.2 (A), U1.14 (A5), U3.4 (A2)
/CA6: D6.2 (A), U1.15 (A6), U3.3 (A1)
/CA7: D7.2 (A), U1.16 (A7), U3.2 (A0)
/CA8: D8.2 (A), U1.17 (A8), U4.9 (A7)
/CA9: D9.2 (A), U1.18 (A9), U4.8 (A6)
/CA10: D10.2 (A), U1.19 (A10), U4.7 (A5)
/CA11: D11.2 (A), U1.20 (A11), U4.6 (A4)
/CA12: D12.2 (A), U1.22 (A12), U4.5 (A3)
/CA13: D13.2 (A), U1.23 (A13), U4.4 (A2)
/CA14: D14.2 (A), U1.24 (A14), U4.3 (A1)
/CA15: D15.2 (A), U1.25 (A15), U4.2 (A0)
/CD0: U1.33 (D0), U2.11 (B7), U5.18 (B0), U6.18 (B0), U7.3 (D0), U8.3 (D0)
/CD1: U1.32 (D1), U2.12 (B6), U5.17 (B1), U6.17 (B1), U7.4 (D1), U8.4 (D1)
/CD2: U1.31 (D2), U2.13 (B5), U5.16 (B2), U6.16 (B2), U7.7 (D2), U8.7 (D2)
/CD3: U1.30 (D3), U2.14 (B4), U5.15 (B3), U6.15 (B3), U7.8 (D3), U8.8 (D3)
/CD4: U1.29 (D4), U2.15 (B3), U5.14 (B4), U6.14 (B4), U7.13 (D4), U8.13 (D4)
/CD5: U1.28 (D5), U2.16 (B2), U5.13 (B5), U6.13 (B5), U7.14 (D5), U8.14 (D5)
/CD6: U1.27 (D6), U2.17 (B1), U5.12 (B6), U6.12 (B6), U7.17 (D6), U8.17 (D6)
/CD7: U1.26 (D7), U2.18 (B0), U5.11 (B7), U6.11 (B7), U7.18 (D7), U8.18 (D7)
/D0: J1.39 (D0), J4.38 (D0), U2.9 (A7)
/D1: J1.38 (D1), J4.37 (D1), U2.8 (A6)
/D2: J1.37 (D2), J4.36 (D2), U2.7 (A5)
/D3: J1.36 (D3), J4.35 (D3), U2.6 (A4)
/D4: J1.35 (D4), J4.34 (D4), U2.5 (A3)
/D5: J1.34 (D5), J4.33 (D5), U2.4 (A2)
/D6: J1.33 (D6), J4.32 (D6), U2.3 (A1)
/D7: J1.32 (D7), J4.31 (D7), U2.2 (A0)
/DAT0: U8.2 (Q0), U11.2
/DAT1: U8.5 (Q1), U11.5
/DAT2: U8.6 (Q2), U11.9
/DAT3: U8.9 (Q3), U11.12
/DAT4: U8.12 (Q4), U12.2
/DAT5: U8.15 (Q5), U12.5
/DAT6: U8.16 (Q6), U12.9
/DAT7: U8.19 (Q7), U12.12
/DIR0: U5.2 (A0), U7.2 (Q0), U11.1
/DIR1: U5.3 (A1), U7.5 (Q1), U11.4
/DIR2: U5.4 (A2), U7.6 (Q2), U11.10
/DIR3: U5.5 (A3), U7.9 (Q3), U11.13
/DIR4: U5.6 (A4), U7.12 (Q4), U12.1
/DIR5: U5.7 (A5), U7.15 (Q5), U12.4
/DIR6: U5.8 (A6), U7.16 (Q6), U12.10
/DIR7: U5.9 (A7), U7.19 (Q7), U12.13
/P0: J1.31 (P0), J4.30 (P0), U6.2 (A0), U11.3
/P1: J1.30 (P1), J4.29 (P1), U6.3 (A1), U11.6
/P2: J1.29 (P2), J4.28 (P2), U6.4 (A2), U11.8
/P3: J1.28 (P3), J4.27 (P3), U6.5 (A3), U11.11
/P4: J1.27 (P4), J4.26 (P4), U6.6 (A4), U12.3
/P5: J4.25 (P5), JP11.1 (A), U6.7 (A5), U12.6
/P6: J4.24 (P6), JP13.1 (A), JP17.1 (A), U6.8 (A6), U12.8
/P7: JP18.1 (A), JP20.1 (A), U6.9 (A7), U12.11
/PHI0: J1.1 (PH0), J4.1 (PHI0IN), JP6.1 (A), JP10.1 (A), U1.37 (PHI0IN)
/PHI2: JP3.1 (A), U10.11
/RDY: J4.2 (RDY), JP2.1 (A), JP12.1 (A), U1.2 (RDY)
/~0000-0001: D1.1 (K), D2.1 (K), D3.1 (K), D4.1 (K), D5.1 (K), D6.1 (K), D7.1 (K), D8.1 (K), D9.1 (K), D10.1 (K), D11.1 (K), D12.1 (K), D13.1 (K), D14.1 (K), D15.1 (K), D16.1 (K), R2.1, U9.4 (E1), U10.10
/~0000_RD: U5.19 (CE), U9.9 (O6)
/~0000_WR: U7.11 (Cp), U9.11 (O4)
/~0001_RD: U6.19 (CE), U9.7 (O7)
/~0001_WR: U8.11 (Cp), U9.10 (O5)
/~6502RW: U1.34 (R/~W), U2.1 (A->B), U9.2 (A1), U10.2, U13.3 (D)
/~8501RW: JP9.1 (A), U13.4 (Q)
/~AEC: J1.5 (AEC), J4.5 (~AEC), U10.1, U10.4
/~GATEIN: JP21.1 (A), U13.1 (LE)
/~IRQ: J4.3 (~IRQ), JP8.1 (A), JP16.1 (A), U1.4 (~IRQ)
/~NMI: J4.4 (~NMI), JP14.1 (A), R5.2, U1.6 (~NMI)
/~RESET: J1.42 (RES), J4.40 (~RESET), JP4.1 (A), JP5.1 (A), U1.40 (~RESET), U7.1 (~Mr), U8.1 (~Mr)
/~RW: J4.39 (R/~W), JP7.1 (A), U10.3
GND: C1.2, C2.2, C3.2, C4.2, C5.2, C6.2, C7.2, J1.21 (GND), J4.21 (GND), JP1.1 (A), JP22.1 (A), R2.2, U1.21 (GND), U2.10 (GND), U3.10 (GND), U4.10 (GND), U5.10 (GND), U6.10 (GND), U7.10 (GND), U8.10 (GND), U9.5 (E2), U9.8 (GND), U10.5, U10.7 (GND), U11.7 (GND), U12.7 (GND), U13.2 (GND)
unnamed: C7.1, D17.1 (K), U13.5 (VCC)
unnamed: J1.2 (RDY/RES/PH0), JP2.2 (B), JP4.2 (B), JP6.2 (B)
unnamed: J1.3 (IRQ/PH0/RDY), JP8.2 (B), JP10.2 (B), JP12.2 (B)
unnamed: J1.4 (NMI/IRQ/IRQ), JP14.2 (B), JP16.2 (B)
unnamed: J1.23 (GND/A15/A15), JP22.2 (B), JP23.2 (B)
unnamed: J1.24 (A14/P7/GATEIN), JP19.2 (B), JP20.2 (B), JP21.2 (B)
unnamed: J1.25 (A15/P6/P7), JP15.2 (B), JP17.2 (B), JP18.2 (B)
unnamed: J1.26 (P5/P5/P6), JP11.2 (B), JP13.2 (B)
unnamed: J1.40 (RW/RW/8501RW), JP7.2 (B), JP9.2 (B)
unnamed: J1.41 (PH2/PH2/RES), JP3.2 (B), JP5.2 (B)
unnamed: JP1.2 (B), U1.1 (GND)
unnamed: R3.2, U2.19 (CE), U10.8
unnamed: R4.2, U1.36 (NC)
unnamed: U1.39 (PHI2OUT), U10.12
VCC: C1.1, C2.1, C3.1, C4.1, C5.1, C6.1, D17.2 (A), J1.6 (VCC), J4.6 (VCC), R1.1, R3.1, R4.1, R5.1, U1.8 (VCC), U1.38 (~S0), U2.20 (VCC), U3.1 (A->B), U3.20 (VCC), U4.1 (A->B), U4.20 (VCC), U5.1 (A->B), U5.20 (VCC), U6.1 (A->B), U6.20 (VCC), U7.20 (VCC), U8.20 (VCC), U9.3 (A2), U9.6 (E3), U9.16 (VCC), U10.13, U10.14 (VCC), U11.14 (VCC), U12.14 (VCC)

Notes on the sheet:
Only needed for 8501
Need to solder the 6502 directly and/or use headers without the plastic piece in order for the module to fit in a Plus4 under the keyboard. C16 on the other hand, has plenty of height.
8500 is equivalent to 6510. 7501 is equivalent to 8501.
Only open JP1 for WDC W65C02, not other 65C02. Using a *65C02 will result in reduced software compatibility due to CPU bugs fixed and undocumented opcodes altered, which are exploited by some software/games/demos.
Clock buffer added in Rev2. Should fix C64 compatibility issues, and maybe some others. Thanks to Ray of Retro Tech Insanity.
For *65C02 support
Solderjumper legend: A = 6510 B = 6510T C = 8501 For 6510, headers are at J1 pins 1-20 and 23-42. For 6510T and 8501, headers are at J1 pins 2-21 and 22-41. For 8502, headers are at J4, and jumpers don't matter.

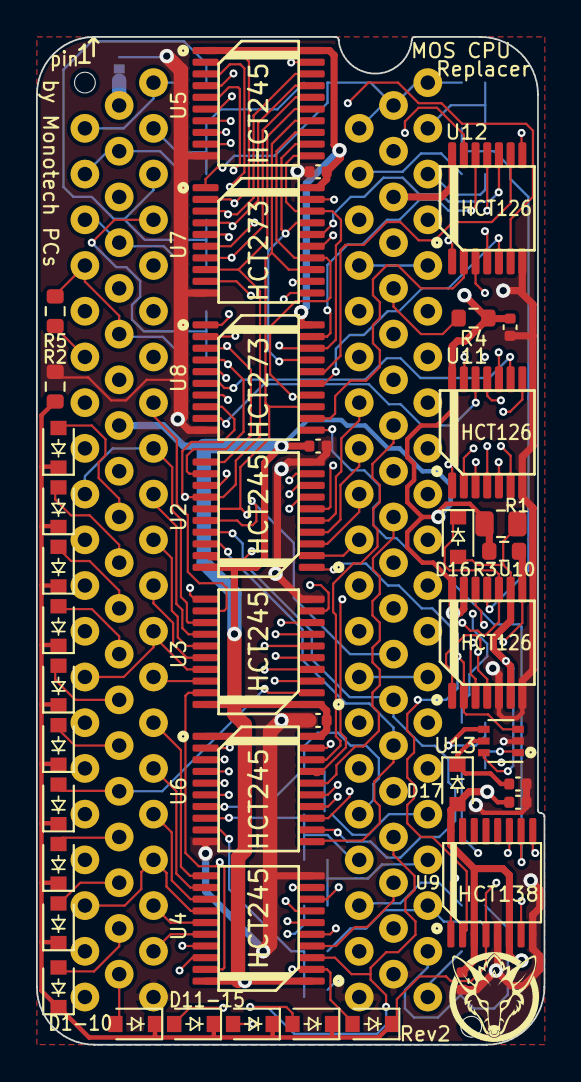
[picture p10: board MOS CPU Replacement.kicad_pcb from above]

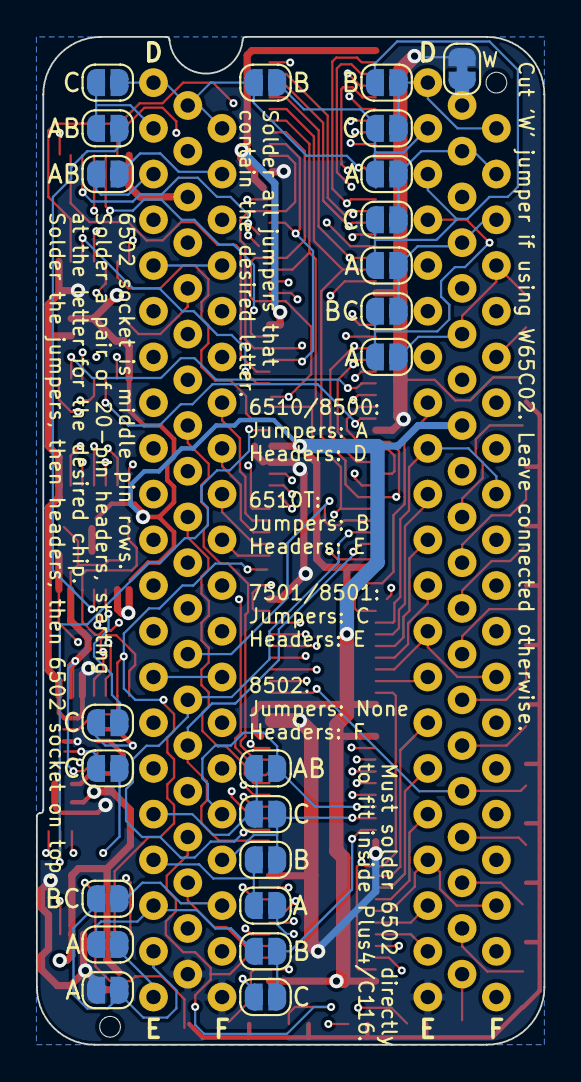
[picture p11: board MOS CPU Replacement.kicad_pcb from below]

Board: 4 copper layers, 28.2 x 56.0 mm, 68 parts (23 on the bottom side), 105 nets.

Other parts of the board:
LOGO1: LOGO
